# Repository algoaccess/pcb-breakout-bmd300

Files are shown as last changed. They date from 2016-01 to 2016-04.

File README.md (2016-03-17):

# pcb-breakout-bmd300

Pin breakout of the Rigado BMD-300 module based on Nordic NRF52 to through-hole pin headers for prototyping.

##PCB Design software and addons used

1. Eagle 7.5.0 standard but freeware should work too
2. BMD-300 library by [Rigado](https://www.rigado.com/product/bmd-300/) (in repo as BMD-300.lbr)

##Images

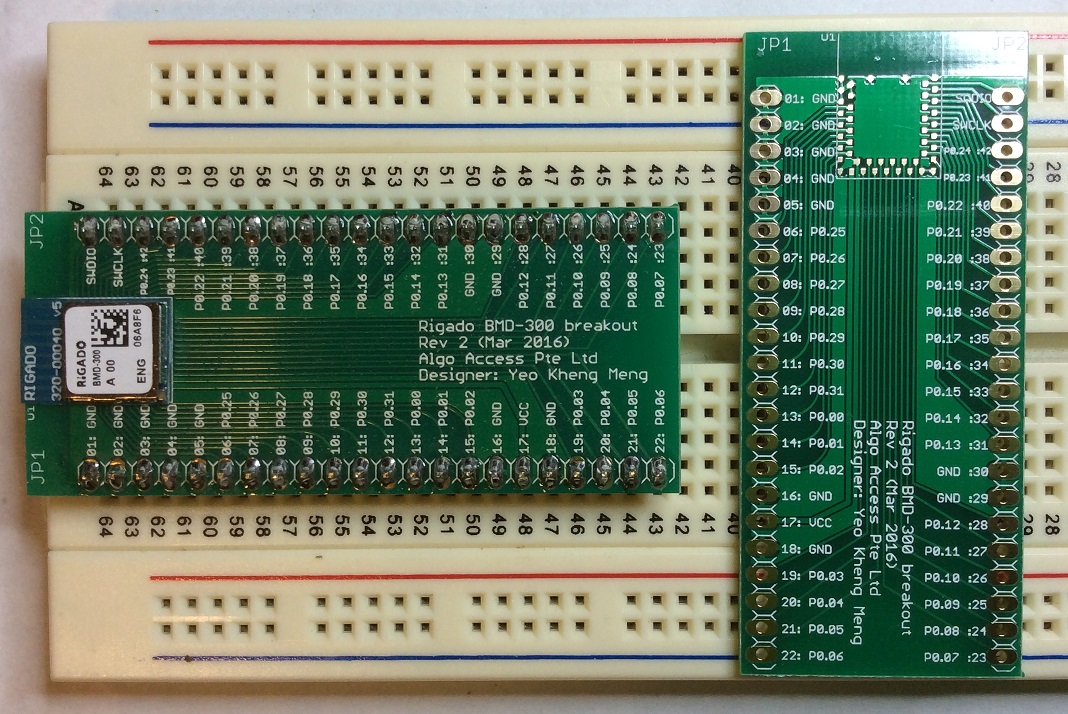
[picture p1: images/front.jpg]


This is the Rev 1 version where there is an error in Rigado's library between Pin 30 and 31 as raised by this issue [here](https://github.com/algoaccess/pcb-breakout-bmd300/issues/1). I have updated to the lastest library by Rigado in Rev 2.

##Schematic drawings
Images are exported from Eagle at 600dpi.

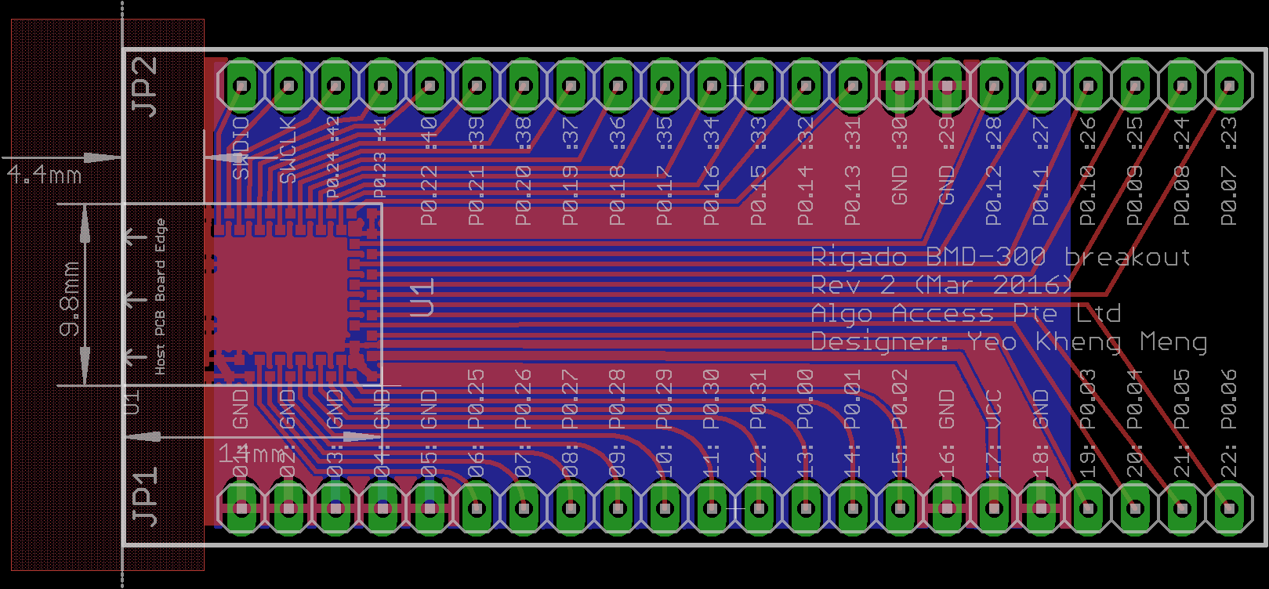
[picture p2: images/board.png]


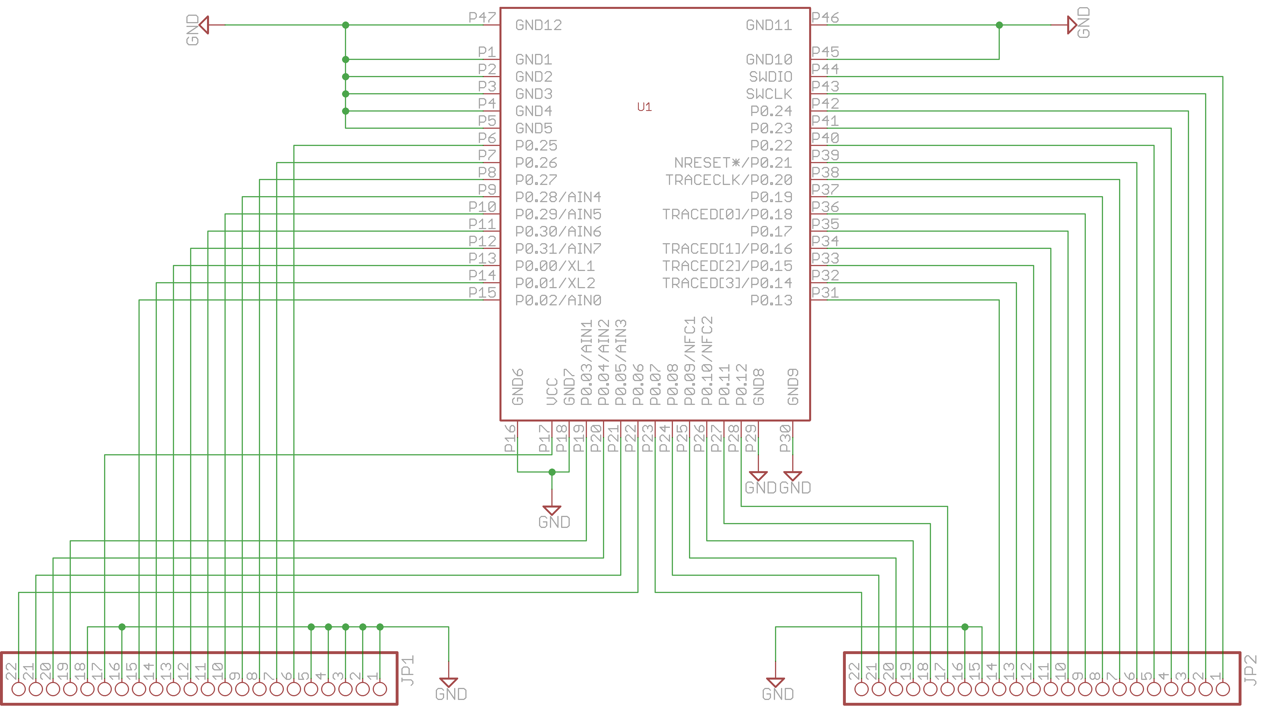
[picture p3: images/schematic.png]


##Parts required

The BMD-300 is still currently sampling and can be requested direct from the manufacturer [Rigado](https://www.rigado.com/product/bmd-300/)

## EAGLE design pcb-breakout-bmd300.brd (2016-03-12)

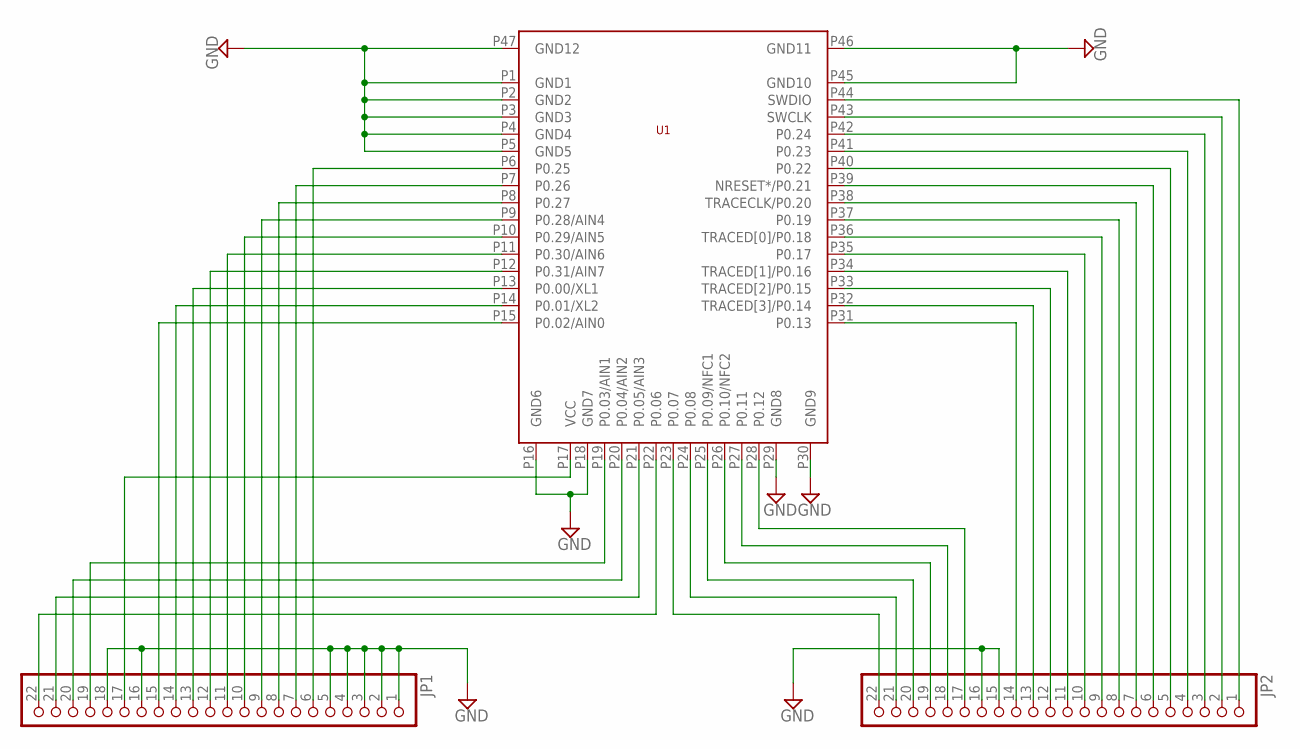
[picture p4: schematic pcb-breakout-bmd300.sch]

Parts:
JP1, JP2: PINHD-1X22; 1X22
U1: BMD-300

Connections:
GND: JP1.1, JP1.2, JP1.3, JP1.4, JP1.5, JP1.16, JP1.18, JP2.15, JP2.16, U1.P1 (GND1), U1.P2 (GND2), U1.P3 (GND3), U1.P4 (GND4), U1.P5 (GND5), U1.P16 (GND6), U1.P18 (GND7), U1.P29 (GND8), U1.P30 (GND9), U1.P45 (GND10), U1.P46 (GND11), U1.P47 (GND12)
unnamed: JP1.6, U1.P6 (P0.25)
unnamed: JP1.7, U1.P7 (P0.26)
unnamed: JP1.8, U1.P8 (P0.27)
unnamed: JP1.9, U1.P9 (P0.28/AIN4)
unnamed: JP1.10, U1.P10 (P0.29/AIN5)
unnamed: JP1.11, U1.P11 (P0.30/AIN6)
unnamed: JP1.12, U1.P12 (P0.31/AIN7)
unnamed: JP1.13, U1.P13 (P0.00/XL1)
unnamed: JP1.14, U1.P14 (P0.01/XL2)
unnamed: JP1.15, U1.P15 (P0.02/AIN0)
unnamed: JP1.17, U1.P17 (VCC)
unnamed: JP1.19, U1.P19 (P0.03/AIN1)
unnamed: JP1.20, U1.P20 (P0.04/AIN2)
unnamed: JP1.21, U1.P21 (P0.05/AIN3)
unnamed: JP1.22, U1.P22 (P0.06)
unnamed: JP2.22, U1.P23 (P0.07)
unnamed: JP2.21, U1.P24 (P0.08)
unnamed: JP2.20, U1.P25 (P0.09/NFC1)
unnamed: JP2.19, U1.P26 (P0.10/NFC2)
unnamed: JP2.18, U1.P27 (P0.11)
unnamed: JP2.17, U1.P28 (P0.12)
unnamed: JP2.14, U1.P31 (P0.13)
unnamed: JP2.13, U1.P32 (TRACED[3]/P0.14)
unnamed: JP2.12, U1.P33 (TRACED[2]/P0.15)
unnamed: JP2.11, U1.P34 (TRACED[1]/P0.16)
unnamed: JP2.10, U1.P35 (P0.17)
unnamed: JP2.9, U1.P36 (TRACED[0]/P0.18)
unnamed: JP2.8, U1.P37 (P0.19)
unnamed: JP2.7, U1.P38 (TRACECLK/P0.20)
unnamed: JP2.6, U1.P39 (NRESET*/P0.21)
unnamed: JP2.5, U1.P40 (P0.22)
unnamed: JP2.4, U1.P41 (P0.23)
unnamed: JP2.3, U1.P42 (P0.24)
unnamed: JP2.2, U1.P43 (SWCLK)
unnamed: JP2.1, U1.P44 (SWDIO)

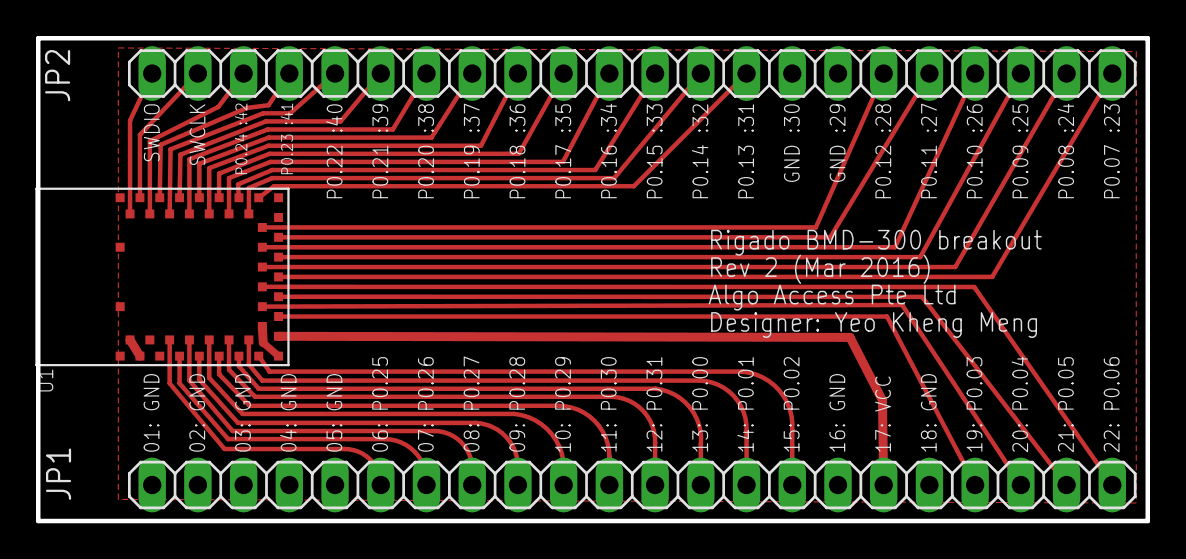
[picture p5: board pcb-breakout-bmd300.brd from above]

Board: 2 copper layers, 61.6 x 26.8 mm, 3 parts (0 on the bottom side), 36 nets.

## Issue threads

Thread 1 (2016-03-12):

Pins 30 and 31 are backwards

dcnichols, 2016-03-12:
Hi yeokm1,

The BMD-300 package has an error on it where pin30 and pin 31 have their location swapped. You can redownload the fixed eagle library part from the Rigado BMD-300 page, or fixed the package in your library (the symbol and mapping are correct, just the package is wrong). For your breakout board, this means that P0.13 is grounded, and the pin labeled P0.13 : P31 is actually a ground (through the module).

yeokm1, 2016-03-12:
Thanks for pointing our the error! I have adjusted my board to use the newer library.

Closed 2016-03-12.

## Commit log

2016-01-27 label rename
    [pcb-breakout-bmd300.brd]
2016-01-27 rev 1 gerber
2016-03-12 Downloaded updated Eagle library from Rigado. Thanks to issue created here. https://github.com/algoaccess/pcb-breakout-bmd300/issues/1
    [pcb-breakout-bmd300.brd, pcb-breakout-bmd300.sch]
